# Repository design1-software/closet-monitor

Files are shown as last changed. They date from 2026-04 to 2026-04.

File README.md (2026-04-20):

# Closet Monitor

An end-to-end IoT data pipeline for monitoring my home lab network closet — and the first node in a broader smart-home observability platform built around Home Assistant.

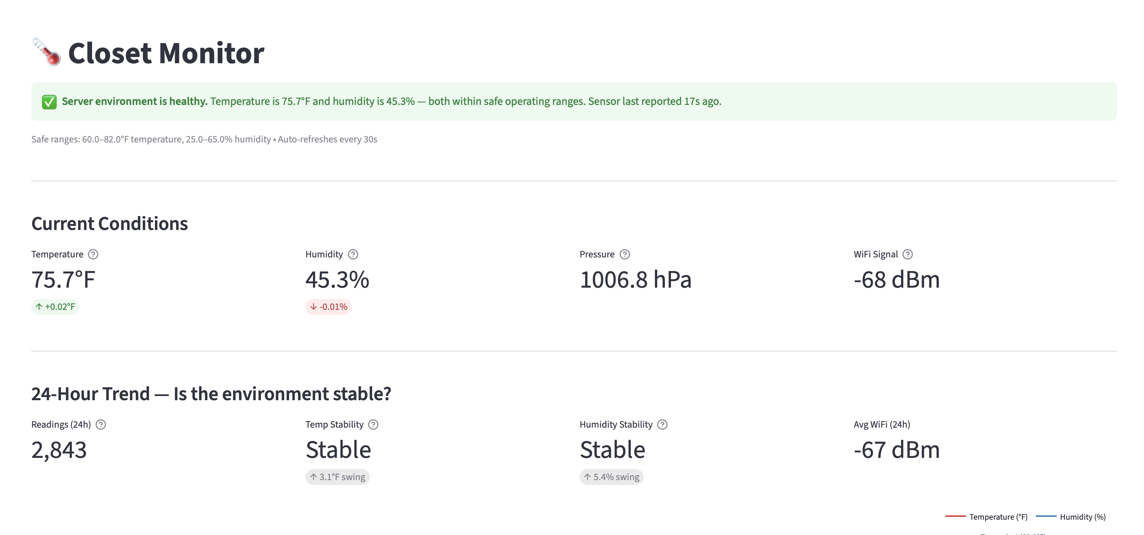
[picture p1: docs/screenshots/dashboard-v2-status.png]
Dashboard Status


*The dashboard leads with the answer: "Should I worry?" Green means all conditions are within safe operating ranges. Current readings, stability assessment, and safe-range thresholds are visible at a glance.*

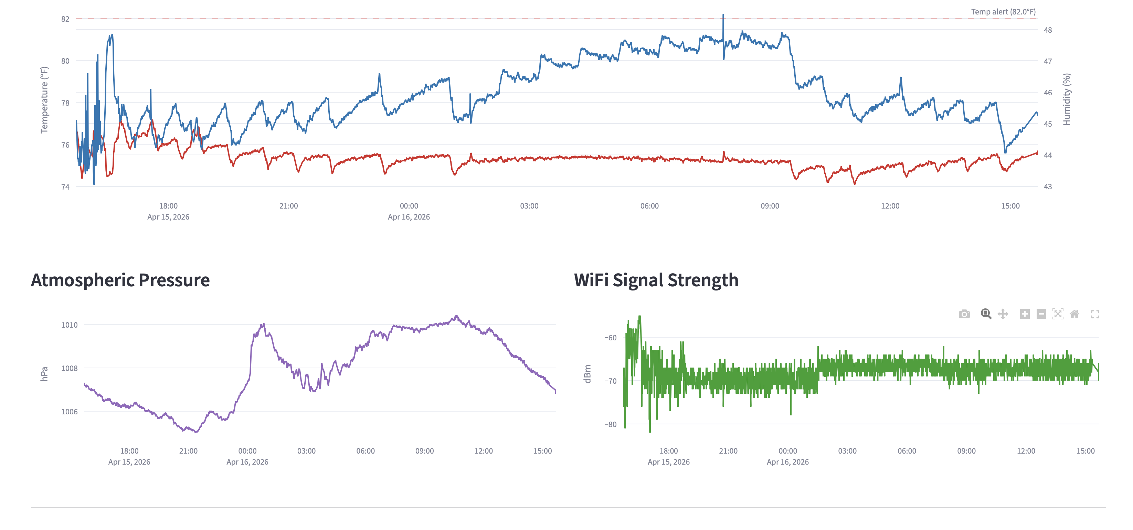
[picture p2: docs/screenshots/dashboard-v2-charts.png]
Dashboard Charts


*24-hour interactive charts for temperature, humidity, pressure, and WiFi signal. The red dashed line marks the 82°F alert threshold — visible context for how close current conditions are to triggering an alert.*

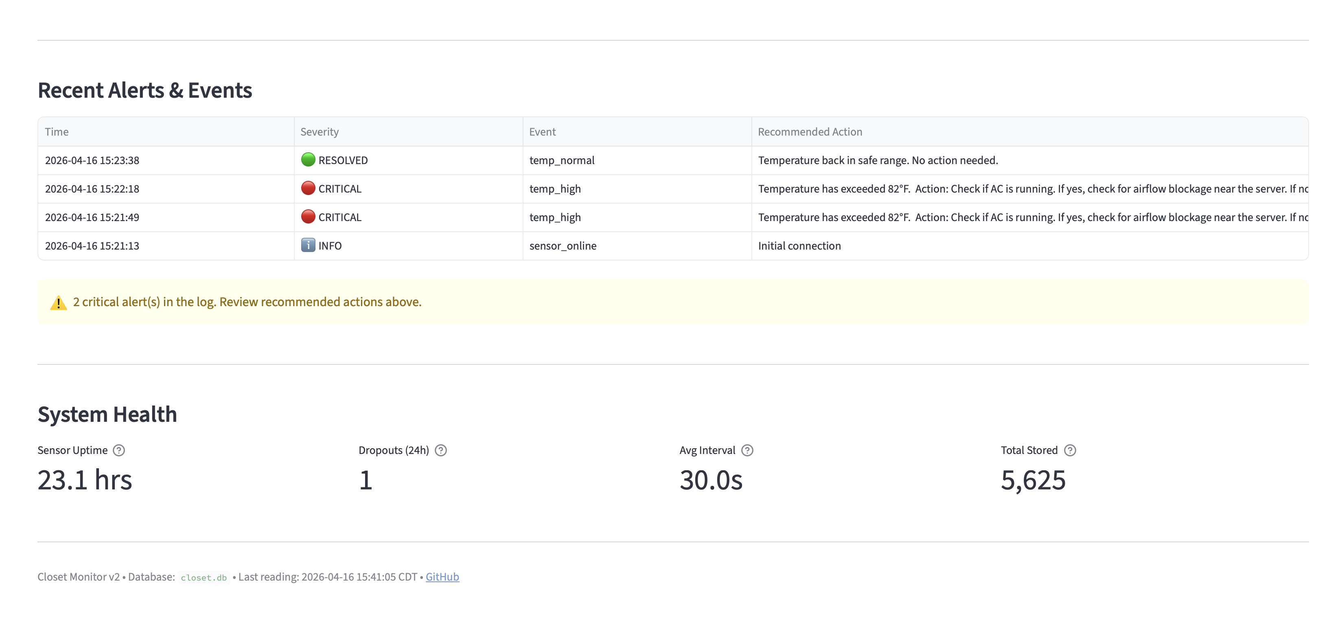
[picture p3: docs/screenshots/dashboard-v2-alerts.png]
Dashboard Alerts


*Incident log with color-coded severity badges and recommended actions for each event. System health metrics at the bottom answer "can I trust this data?" — sensor uptime, dropout count, average interval, total readings stored.*

## The story behind this project

This project started as a single-evening exercise: wire up a microcontroller to a temperature sensor and prove I could do basic embedded work. By the time I had the firmware working and overnight data flowing, I realized the *interesting* problem wasn't the sensor — it was what to do with the telemetry it produced.

So I pivoted.

What was a one-night embedded project became a multi-stage pipeline spanning **embedded systems → networking → backend services → data persistence → exploratory analysis → dashboarding → alerting**. Every layer is a deliberate learning surface. The goal isn't just to monitor my closet — it's to walk a complete data lifecycle with one cohesive dataset I actually understand and care about, then use it as the proving ground for a larger smart-home platform.

The closet is real. My home server lives there, running a production MCP (Model Context Protocol) server and a Meta Engagement automation pipeline. A laptop running 24/7 in an enclosed space deserves observability, and now it has it.

## What this project answers

Every dashboard, alert, and analysis in this project exists to answer a specific question — the same way production monitoring serves stakeholders in a corporate environment.

| Question | Who asks it | How it's answered |
|---|---|---|
| "Is my server environment safe right now?" | Server operator | Dashboard: green/red status banner with plain-English assessment |
| "Has anything happened that requires attention?" | Server operator | Alert listener: macOS notifications with action runbooks + incident log |
| "How efficiently is my HVAC cycling?" | Homeowner | Analysis: cycle frequency, duration, time-of-day patterns |
| "Is the environment stable or volatile?" | Both | Dashboard: stability labels (Stable/Moderate/Volatile) based on 24h swing |
| "What external factors affect my server environment?" | Analyst | Analysis: door events, human presence, time-of-day correlation |
| "Can I trust this monitoring data?" | System operator | Dashboard: sensor uptime, dropout count, average interval |

## Where this is headed

This repo is the foundation for a larger **smart home + home lab observability platform**:

- **Home Assistant on a Raspberry Pi 5** as the central hub, ingesting data from this sensor and other smart devices
- **Ecobee thermostat integration** via Home Assistant, with cross-correlation analysis between the wall thermostat readings and what's actually happening in the closet
- **Three wall-mounted 10-inch tablets** as monitoring and control panels around the house, running Home Assistant's Lovelace UI
- **Multiple sensor projects** feeding into the same data fabric over time

The closet monitor proves out the pipeline pattern. Future sensor projects (door reed switches, motion sensors, current monitors) will reuse this MQTT → broker → database → dashboard architecture.

## Architecture (current)

```
┌─────────────────┐
│  ESP32 + BME280 │  Edge device — embedded C++
└────────┬────────┘
         │ WiFi · MQTT (authenticated)
         ▼
┌─────────────────┐
│ Mosquitto Broker│  Message broker (auth + topic ACLs)
└────────┬────────┘
         │ subscribe (authenticated)
         ▼
┌──────────────────┐    ┌──────────────────┐
│ Python Subscriber│    │  Alert Listener  │
│ paho-mqtt→SQLite │    │ notifications +  │
│                  │    │ runbook actions   │
└────────┬─────────┘    └──────────────────┘
         │
         ▼
┌──────────────────┐
│  SQLite Database │  readings + events + alerts
└────────┬─────────┘
         │
   ┌─────┴─────┬──────────────┐
   ▼           ▼              ▼
Jupyter    Streamlit      MCP tool
analysis   dashboard      (planned)
```

## Architecture (target)

```
┌─────────────────┐    ┌─────────────────┐
│  ESP32 + BME280 │    │ Ecobee Thermostat│
│ (closet sensor) │    │  (whole house)   │
└────────┬────────┘    └────────┬─────────┘
         │ MQTT (TLS)            │ Cloud API
         ▼                       ▼
┌─────────────────────────────────────────┐
│  Home Assistant on Raspberry Pi 5       │
│  + Mosquitto broker (production, TLS)   │
│  + SQLite/Postgres for long-term data   │
└────────┬────────────────────────────────┘
         │
   ┌─────┴──────┬──────────────┬──────────────┐
   ▼            ▼              ▼              ▼
Tablet UIs   Lovelace      Cross-source   AI insights
(3 around    dashboards    analytics      (anomaly
 the house)                (HA + closet)  detection)
```

## Hardware

- **ESP32-WROOM-32** (Teyleten 38-pin, USB-C) — dual-core 240 MHz microcontroller with WiFi + Bluetooth
- **BME280 sensor** (SHILLEHTEK pre-soldered, 3.3V, I²C at 0x76) — temperature, humidity, pressure
- **4 female-to-female Dupont jumper wires** — direct ESP32-to-sensor connection (no breadboard)
- **3D-printable enclosure** — two-piece design (ESP32 cradle + remote sensor pod), STL files in `case-design/`

### Wiring

| BME280 Pin | ESP32 Pin |
|---|---|
| VCC | 3V3 |
| GND | GND |
| SCL | GPIO 22 |
| SDA | GPIO 21 |

## Software stack

- **Firmware:** Arduino C++ using PubSubClient (MQTT) and Adafruit BME280 libraries
- **Broker:** Eclipse Mosquitto 2.x with authentication and topic-level ACLs
- **Subscriber:** Python 3 with paho-mqtt and python-dotenv
- **Alert Listener:** Python 3 with macOS native notifications, action runbooks, SQLite logging
- **Database:** SQLite 3 (readings, events, and alerts tables)
- **Analysis:** Python with pandas, matplotlib, seaborn, scipy (Jupyter notebooks)
- **Dashboard:** Streamlit + Plotly, framed around stakeholder questions
- **Toolchain:** `arduino-cli` for firmware, virtualenv for Python dependencies

## MQTT topics

| Topic | Payload | Frequency |
|---|---|---|
| `home/closet/status` | `online` / `offline` (retained, LWT) | On connect/disconnect |
| `home/closet/environment` | JSON (temp, humidity, pressure, RSSI, uptime) | Every 30s |
| `home/closet/alerts/temperature` | JSON alert state (retained, edge-triggered) | On threshold cross |
| `home/closet/alerts/humidity` | JSON alert state (retained, edge-triggered) | On threshold cross |

The `home/` prefix and standard payload format are intentionally Home Assistant-friendly. When the platform comes online, HA will subscribe to these topics with no firmware changes required.

### Example payload

```json
{
  "temp_f": 76.71,
  "temp_c": 24.84,
  "humidity": 41.44,
  "pressure_hpa": 1009.71,
  "rssi": -72,
  "uptime_s": 60
}
```

## Database schema

```sql
CREATE TABLE readings (
    id              INTEGER PRIMARY KEY AUTOINCREMENT,
    received_at     TEXT NOT NULL,
    device_uptime_s INTEGER,
    temp_f          REAL,
    temp_c          REAL,
    humidity        REAL,
    pressure_hpa    REAL,
    rssi            INTEGER
);

CREATE TABLE events (
    id          INTEGER PRIMARY KEY AUTOINCREMENT,
    received_at TEXT NOT NULL,
    topic       TEXT NOT NULL,
    payload     TEXT NOT NULL
);

CREATE TABLE alerts (
    id          INTEGER PRIMARY KEY AUTOINCREMENT,
    received_at TEXT NOT NULL,
    severity    TEXT NOT NULL,
    event_type  TEXT NOT NULL,
    topic       TEXT NOT NULL,
    payload     TEXT NOT NULL,
    action      TEXT
);
```

## Findings so far

After ~48 hours of continuous operation and 5,600+ readings:

- **Zero packet loss** over the full run (intervals ranged 27.5–32.5s, target 30s)
- Temperature held within a tight 5.4°F band with std dev of just 0.91°F — evidence of healthy HVAC behavior
- **15 HVAC cycles automatically detected** using rolling-mean smoothing + scipy peak detection
- Cycle lengths split into two distinct regimes: **short cycles (16–50 min) during evening peak hours**, **long cycles (100+ min) overnight** — consistent with healthy outside-temperature-driven HVAC behavior
- Average temperature swing per cycle: 1.29°F (tight thermostat control)
- **Rate-of-change anomaly detection** identified 31 rapid temperature events and 67 rapid humidity events using a rolling z-score method
- Detected a **door-closing event at approximately 1:40 AM** from its thermal signature: sudden temperature rise (+1.68°F over 3 minutes) with simultaneous humidity drop, consistent with sealing a warmer, drier room
- Multiple brief humidity spike events (z>10) correlated with human presence and activity in the bedroom

## Alert system

Every alert includes three things: **what happened, why it matters, and what to do about it.**

| Alert | Severity | Action |
|---|---|---|
| Temp > 82°F | CRITICAL | Check if AC is running. If yes, investigate airflow blockage. If no, check thermostat. |
| Temp < 60°F | WARNING | Check if heating is running. Possible HVAC failure. |
| Humidity > 65% | CRITICAL | Check for water intrusion or AC drain issue. Inspect equipment for condensation. |
| Humidity < 25% | WARNING | Consider humidifier. Avoid touching components without grounding. |
| Sensor offline > 5 min | WARNING | Check USB power to ESP32. Check WiFi. Press EN button to reset. |

Alerts are delivered via macOS desktop notifications and logged to both a flat file (`alerts.log`) and the SQLite `alerts` table for dashboard display and historical analysis.

## Security

Defense-in-depth approach: network-layer isolation via Cisco ACLs **plus** application-layer authentication and authorization via Mosquitto.

### Network layer (Cisco ACLs)

The ESP32 sensor will operate on **VLAN 31 (IOT-AUTO)** once the MQTT broker migrates to the Raspberry Pi. The IOT-AUTO ACL restricts traffic to:

- **DNS (UDP/TCP 53)** to Pi-hole only (192.168.10.16)
- **MQTT (TCP 1883, 8883)** to the Pi only (192.168.10.16)
- **All other traffic denied** — no internet, no access to server VLAN, no lateral movement

A compromised ESP32 on IOT-AUTO can only reach the MQTT broker and DNS. It cannot scan the network, access the server, or phone home to an external endpoint.

### Application layer (Mosquitto auth + ACLs)

MQTT connections require username/password authentication. Anonymous access is denied.

| User | Purpose | Permissions |
|---|---|---|
| `closet-sensor` | ESP32 device identity | **Write only** to `home/closet/environment`, `home/closet/status`, `home/closet/alerts/*` |
| `closet-subscriber` | Python services (subscriber + alert listener) | **Read only** on `home/closet/#`, write to `home/closet/status` (for testing) |

**What this prevents:**

| Attack | Without auth | With auth + ACLs |
|---|---|---|
| Rogue device publishes fake "everything is fine" readings | ✅ Possible — anyone on the network can publish | ❌ Blocked — must authenticate, and only `closet-sensor` can write to environment topic |
| Rogue device publishes fake alerts (false CRITICAL notifications) | ✅ Possible | ❌ Blocked — only `closet-sensor` can write to alert topics |
| Rogue device subscribes and eavesdrops on sensor data | ✅ Possible | ❌ Blocked — must authenticate as `closet-subscriber` |
| Compromised subscriber publishes fake readings | ✅ Possible | ❌ Blocked — `closet-subscriber` has read-only access to environment topic |
| Compromised IoT device on VLAN 31 scans the network | ❌ Already blocked by Cisco ACL | ❌ Blocked at network layer before reaching MQTT |

### Credential management

- ESP32 credentials are in `config.h` (gitignored, never committed)
- Python credentials are in `.env` (gitignored, never committed)
- Template files (`config.example.h`, `.env.example`) are committed with placeholder values
- Mosquitto password file uses hashed passwords (not plaintext)

### Encryption roadmap

Currently MQTT traffic is unencrypted (plain TCP on port 1883). When the broker migrates to the Raspberry Pi, TLS will be added:

- Mosquitto configured for MQTT over TLS on port 8883
- ESP32 firmware updated to use `WiFiClientSecure` with certificate pinning
- The IOT-AUTO ACL already permits port 8883 in anticipation of this migration

This will complete the security stack: **network isolation (VLAN + ACL) → authentication (username/password) → authorization (topic ACLs) → encryption (TLS).**

## Setup

### Firmware

1. Copy `config.example.h` to `config.h` and fill in WiFi credentials, MQTT broker IP, and MQTT credentials
2. Install toolchain:
   ```bash
   brew install arduino-cli mosquitto
   arduino-cli core install esp32:esp32
   arduino-cli lib install "PubSubClient" "Adafruit BME280 Library" "Adafruit Unified Sensor"
   ```
3. Compile and upload (hold BOOT button on ESP32 during upload):
   ```bash
   arduino-cli compile --fqbn esp32:esp32:esp32 .
   arduino-cli upload -p /dev/cu.usbserial-0001 --fqbn esp32:esp32:esp32 .
   ```

### Mosquitto broker

```bash
brew install mosquitto
# Create password file with device and subscriber users
mosquitto_passwd -c /opt/homebrew/etc/mosquitto/passwordfile closet-sensor
mosquitto_passwd /opt/homebrew/etc/mosquitto/passwordfile closet-subscriber
# Copy aclfile to /opt/homebrew/etc/mosquitto/aclfile
# Configure mosquitto.conf:
#   listener 1883 0.0.0.0
#   allow_anonymous false
#   password_file /opt/homebrew/etc/mosquitto/passwordfile
#   acl_file /opt/homebrew/etc/mosquitto/aclfile
brew services start mosquitto
```

### Subscriber + Alert Listener

```bash
cd subscriber
python3 -m venv venv
source venv/bin/activate
pip install -r requirements.txt
cp .env.example .env       # edit with your broker IP and MQTT credentials

# Terminal 1: data subscriber
python subscriber.py

# Terminal 2: alert listener
python alert_listener.py
```

### Dashboard

```bash
cd subscriber && source venv/bin/activate
cd ../dashboard
streamlit run dashboard.py
# Opens at http://localhost:8501
```

### Analysis

```bash
cd analysis
jupyter lab
```

### Verify the pipeline

```bash
# Authenticated subscribe (replace credentials)
mosquitto_sub -h <broker-ip> -u closet-subscriber -P '<password>' -t "home/closet/#" -v
sqlite3 data/closet.db "SELECT COUNT(*) FROM readings;"
```

## Design decisions

- **JSON payloads** over binary — slightly more bandwidth, massively easier to debug with `mosquitto_sub -v` and to consume from any language. Also Home Assistant-friendly out of the box.
- **Edge-triggered alerts** — alert topics only publish when state changes, avoiding alert spam while still capturing every transition. Retained flag ensures late subscribers see current state.
- **Last Will & Testament** — broker auto-publishes `offline` to `home/closet/status` if the ESP32 disconnects uncleanly.
- **Non-blocking main loop** — uses `millis()` timing instead of `delay()` so the MQTT client can service keepalives and reconnections between sensor reads.
- **Separation of concerns** — credentials live in `config.h` (firmware) and `.env` (subscriber), both gitignored. Example templates are committed.
- **Server-side timestamps** — the subscriber records `received_at` independently of the device's `uptime_s`, so reading order is preserved even if the device reboots.
- **Runbook-based alerting** — every alert includes a recommended action, not just a notification. This mirrors how production incident management systems (PagerDuty, OpsGenie) operate.
- **Dashboard framed around questions, not metrics** — each section answers a specific stakeholder question ("Should I worry?", "What's the trend?", "Has anything happened?", "Can I trust this data?"). This is how business intelligence dashboards are designed in corporate environments.
- **Defense-in-depth security** — MQTT authentication and topic-level ACLs at the application layer, combined with VLAN isolation and Cisco ACLs at the network layer. Neither layer alone is sufficient; together they prevent both network-level and application-level attacks.
- **SQLite over Postgres for the first iteration** — single-file database, zero ops overhead, sufficient throughput for 30s sampling. Migration to Postgres or DuckDB happens when data volumes or query patterns demand it.
- **MQTT topic naming follows the Home Assistant convention** — `home/<location>/<metric>` — so the eventual HA migration is configuration-only, no firmware changes.

## Repository layout

```
closet-monitor/
├── closet-monitor.ino                 # ESP32 firmware
├── config.example.h                   # Firmware config template
├── case-design/
│   ├── esp32_case.scad                # OpenSCAD source (ESP32 enclosure)
│   ├── esp32_case.stl                 # Print-ready STL
│   ├── sensor_pod.scad                # OpenSCAD source (BME280 pod)
│   ├── sensor_pod.stl                 # Print-ready STL
│   └── PRINT_SPEC.md                 # Print settings and service recommendations
├── data/
│   ├── sample-overnight-*.log         # Sample dataset
│   └── closet.db                      # Live SQLite database (gitignored)
├── subscriber/
│   ├── subscriber.py                  # MQTT → SQLite service (authenticated)
│   ├── alert_listener.py             # Alert notifications + runbook actions (authenticated)
│   ├── requirements.txt               # Python dependencies
│   └── .env.example                   # Config template (includes MQTT credentials)
├── analysis/
│   ├── 01-exploratory-analysis.ipynb  # Exploratory data analysis + HVAC cycle detection
│   └── 02-anomaly-detection.ipynb     # Rate-of-change anomaly detection
├── dashboard/
│   └── dashboard.py                   # Streamlit operations dashboard
├── docs/
│   └── screenshots/                   # README assets
└── README.md
```

## Roadmap

### Done
- [x] ESP32 firmware with WiFi + MQTT + BME280
- [x] Threshold-based alerting (edge-triggered)
- [x] Python subscriber with SQLite persistence
- [x] Sample overnight dataset (~955 readings, 8 hours continuous)
- [x] Exploratory analysis: descriptive stats, time-series plots, correlation
- [x] HVAC cycle detection with scipy peak detection
- [x] Cycle length analysis and time-of-day pattern identification
- [x] Rate-of-change anomaly detection with rolling z-score
- [x] Detected real-world events from sensor signatures (door closing, human presence)
- [x] Streamlit dashboard framed around stakeholder questions
- [x] Alert listener with macOS notifications and action runbooks
- [x] 3D-printable case design (ESP32 enclosure + sensor pod)
- [x] MQTT authentication (per-device username/password)
- [x] MQTT topic-level ACLs (write-only sensor, read-only subscriber)

### Next
- [ ] TLS encryption for MQTT (port 8883) during Pi migration
- [ ] Ecobee integration via Home Assistant HomeKit Controller
- [ ] Cross-correlation analysis: closet temp vs. thermostat schedule
- [ ] AI-generated daily summary reports
- [ ] Migrate broker + services to production server (Acer)

### Platform
- [ ] Install Home Assistant on Raspberry Pi 5
- [ ] Connect HA to existing MQTT topics (zero firmware changes)
- [ ] Add ecobee integration through HA
- [ ] Build Lovelace dashboard combining closet sensor + ecobee data
- [ ] Deploy 3 wall-mounted tablets running HA's tablet UI
- [ ] MCP integration so Claude can query the unified data through HA

### Future sensors
- [ ] PIR motion sensor in the closet
- [ ] Door reed switch on the closet door
- [ ] Current sensor on the home server's power cable
- [ ] Additional environmental nodes in other parts of the house

## Why this lives in one repo

The temptation with a project like this is to split it into multiple repos — one for firmware, one for the subscriber service, one for analysis. I'm deliberately keeping them together because the *story* of this project is the integration. Anyone reading this repo can follow a single physical signal — temperature in a closet — through every stage of an end-to-end data system. That narrative is more valuable to me right now than the modularity. When a piece outgrows this layout (likely the Home Assistant integration), it'll move to its own repo with proper boundaries.

## Related infrastructure

This sensor is one node in a broader home lab network documented at [git-init-home-lab](https://github.com/design1-software/git-init-home-lab).

The ESP32 currently connects via the Gorgeous SSID (VLAN 20, TRUSTED) and publishes MQTT to a Mosquitto broker on the MacBook Pro. When Mosquitto migrates to the Raspberry Pi 4B (192.168.10.16, VLAN 10, SERVER), the ESP32 will move to the Gorgeous-Auto SSID (VLAN 31, IOT-AUTO) — a dedicated automation VLAN that permits only MQTT and DNS traffic to the Pi via Cisco ACLs.

## Author

Julius Moore — part of a broader home lab build, developed alongside coursework for B.S. Software Engineering at WGU.

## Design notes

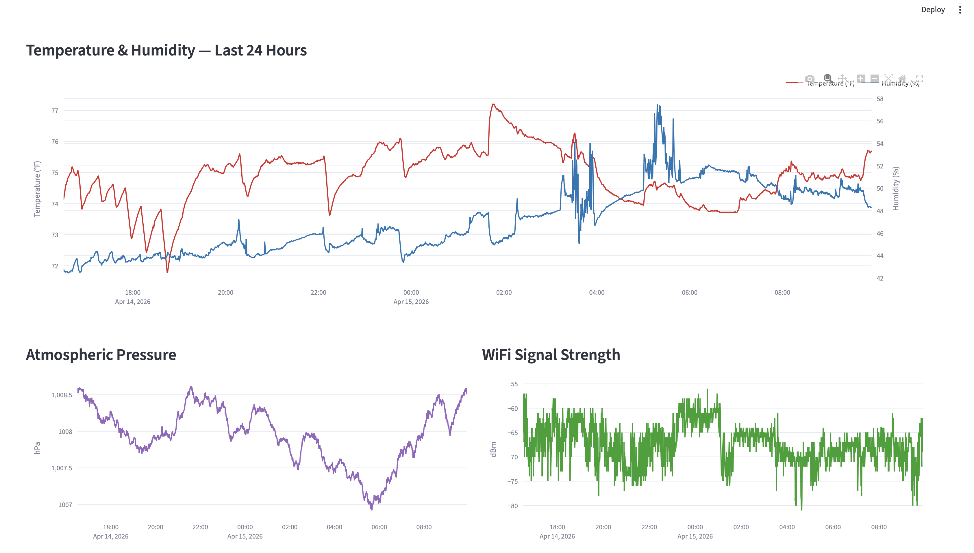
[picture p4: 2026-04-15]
docs/screenshots/hvac-cycles.png

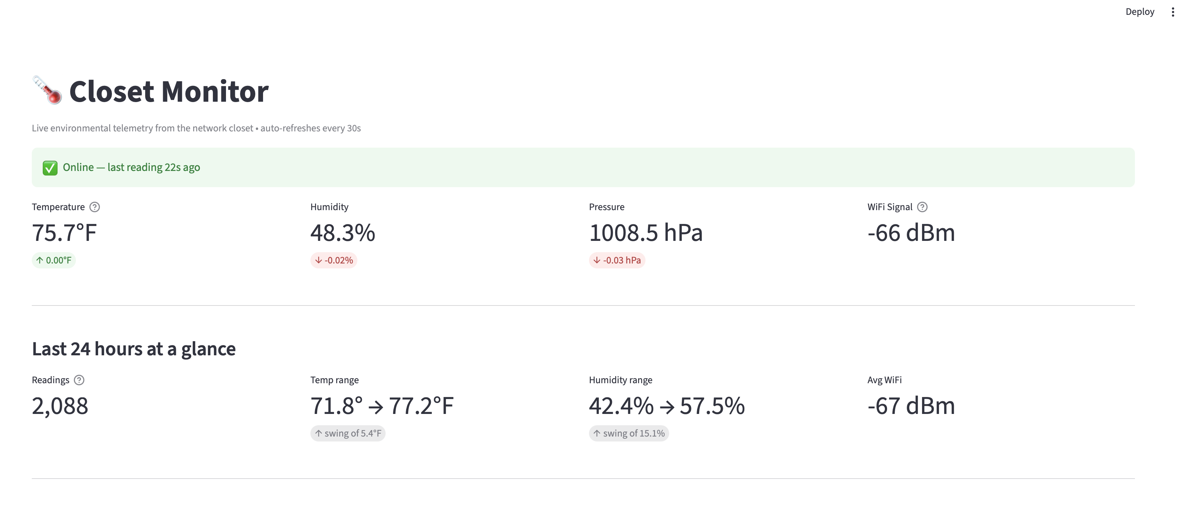
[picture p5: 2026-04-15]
docs/screenshots/dashboard.png

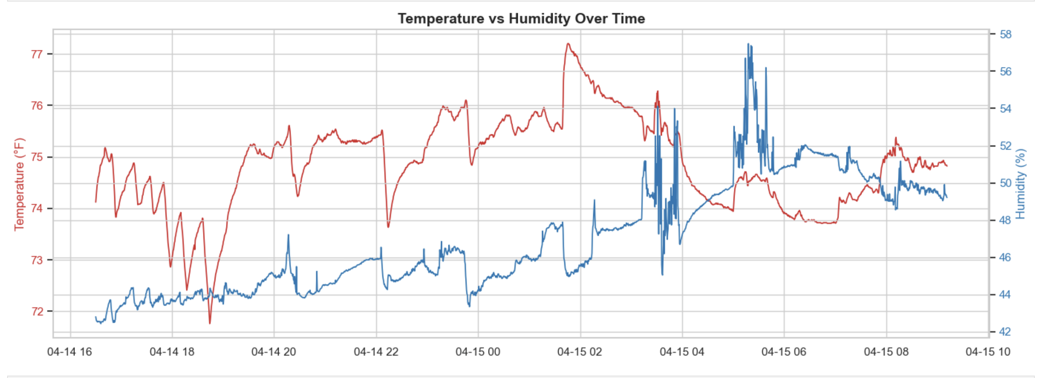
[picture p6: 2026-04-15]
docs/screenshots/time-series.png

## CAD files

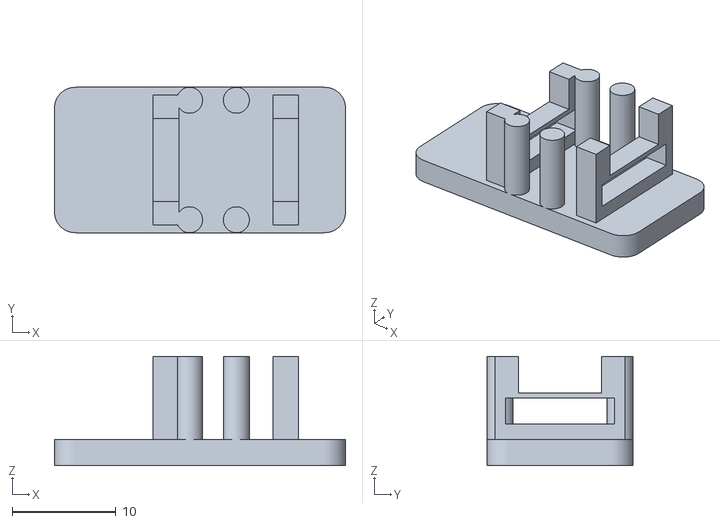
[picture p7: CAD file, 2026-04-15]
case-design/sensor_pod.stl
28.0 x 14.0 x 10.5

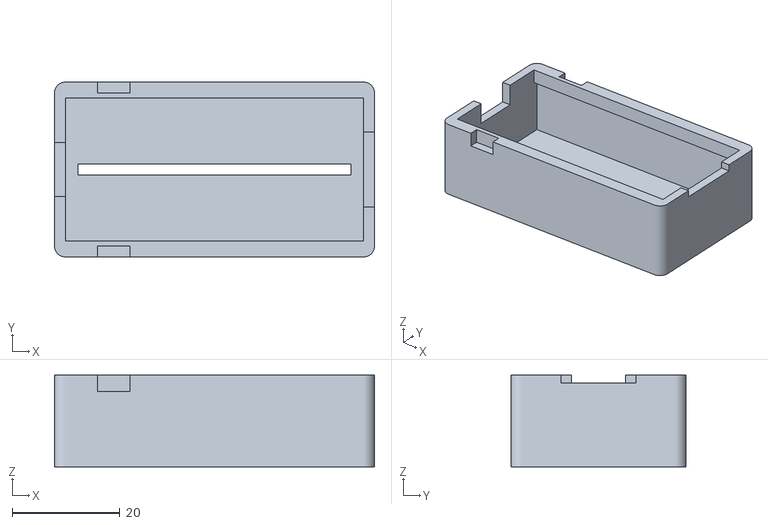
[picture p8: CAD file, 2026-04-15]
case-design/esp32_case.stl
59.5 x 32.5 x 17.1

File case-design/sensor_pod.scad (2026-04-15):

// ============================================================
// BME280 Sensor Pod — Closet Monitor
// ============================================================
// Design: open-air "lantern" style frame that holds the BME280
// breakout board between two end caps with vertical posts —
// maximum airflow on all sides. Flat back for VHB tape.
//
// Board: SHILLEHTEK pre-soldered BME280 breakout
//   Length: ~13mm
//   Width:  ~10mm
//   Thickness: ~2mm with components
//
// Print: PETG, 0.2mm layer, 30% infill, no supports needed
// ============================================================

$fn = 60;

// ---------- TUNABLE PARAMETERS ----------
// BME280 board
board_length = 13.5;
board_width  = 10.5;
board_thick  = 2.5;     // includes the sensor chip on top

// End caps that hold the board
endcap_thick    = 2.5;
endcap_height   = 8;
endcap_width_extra = 2;  // extra width past the board for grip slots

// Posts that connect the two end caps (the "lantern" structure)
post_count   = 4;        // one at each corner
post_diameter = 2.5;
post_spacing  = 9;       // distance between posts (becomes airflow gap)

// Mounting back-plate (flat surface for VHB tape)
backplate_length = 28;
backplate_width  = 14;
backplate_thick  = 2.5;

// Cable exit (where the 4 jumpers come from the ESP32 case)
cable_notch_width  = 8;
cable_notch_height = 4;

// ---------- DERIVED ----------
endcap_total_width = board_width + endcap_width_extra;

// ============================================================
// MAIN ASSEMBLY
// ============================================================
module sensor_pod() {

    // ---------- BACKPLATE (for VHB adhesive mounting) ----------
    translate([-((backplate_length - post_spacing) / 2), -((backplate_width - endcap_total_width) / 2), 0])
        rounded_plate(backplate_length, backplate_width, backplate_thick, r=2);

    // ---------- LEFT END CAP (with PCB slot) ----------
    translate([0, 0, backplate_thick])
        endcap_with_slot();

    // ---------- RIGHT END CAP ----------
    translate([post_spacing + endcap_thick, 0, backplate_thick])
        endcap_with_slot();

    // ---------- CONNECTING POSTS (4 corners) ----------
    // The PCB is held between the two end caps; posts give airflow on all sides
    post_z = backplate_thick;
    post_h = endcap_height;

    // Top-front
    translate([endcap_thick + 1, 0.5, post_z])
        cylinder(h=post_h, d=post_diameter);
    // Top-back
    translate([endcap_thick + 1, endcap_total_width - 0.5, post_z])
        cylinder(h=post_h, d=post_diameter);
    // Bottom-front
    translate([post_spacing - 1, 0.5, post_z])
        cylinder(h=post_h, d=post_diameter);
    // Bottom-back
    translate([post_spacing - 1, endcap_total_width - 0.5, post_z])
        cylinder(h=post_h, d=post_diameter);
}

// End cap with a slot that the BME280 board slides into
module endcap_with_slot() {
    difference() {
        cube([endcap_thick, endcap_total_width, endcap_height]);

        // Slot for the PCB
        translate([-0.5, (endcap_total_width - board_width) / 2, 1.5])
            cube([endcap_thick + 1, board_width, board_thick]);

        // Cable notch on one end cap
        translate([-0.5, (endcap_total_width - cable_notch_width) / 2, endcap_height - cable_notch_height + 0.5])
            cube([endcap_thick + 1, cable_notch_width, cable_notch_height]);
    }
}

// Rounded plate helper
module rounded_plate(l, w, h, r=2) {
    hull() {
        for (x = [r, l - r]) {
            for (y = [r, w - r]) {
                translate([x, y, 0])
                    cylinder(h=h, r=r);
            }
        }
    }
}

// ============================================================
// RENDER
// ============================================================
sensor_pod();

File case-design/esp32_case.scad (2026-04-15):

// ============================================================
// ESP32 Closet Monitor — Main Enclosure
// ============================================================
// Design: side-grip cradle, USB-C accessible, BOOT/EN buttons
// reachable, flat back for 3M VHB tape mounting.
//
// Board: Teyleten ESP32-WROOM-32 38-pin USB-C
//   Length: ~55mm
//   Width:  ~28mm
//   Height: ~13mm (including stacked pin headers below)
//
// Print: PETG, 0.2mm layer, 30% infill, no supports needed
// ============================================================

// ---------- TUNABLE PARAMETERS ----------
$fn = 60;  // smoothness of curves

// Board dimensions (with small clearance)
board_length = 55.5;
board_width  = 28.5;
board_thick  = 1.6;     // PCB only
pin_clearance = 12;     // space below board for pin headers

// Wall thickness
wall = 2.0;

// Side rails that grip the PCB
rail_height = 1.5;      // how much the rail sticks up over the PCB top
rail_grip   = 1.0;      // how far the rail extends inward over the PCB

// USB-C cutout (left end of board)
usb_width  = 10;
usb_height = 5;
usb_y_offset = 0;       // centered on board height

// Cable exit slot for the 4 sensor jumper wires (right end)
cable_slot_width  = 14;
cable_slot_height = 6;

// Button access cutouts (BOOT and EN are on opposite sides near the USB end)
button_cutout_width  = 6;
button_cutout_height = 5;
button_y_from_usb_end = 8;  // approx distance from USB end to buttons

// Vent slots on the bottom (so heat from the regulator can escape)
vent_count = 4;
vent_width = 2;
vent_length = 15;

// ---------- DERIVED ----------
inner_length = board_length;
inner_width  = board_width;
outer_length = inner_length + (2 * wall);
outer_width  = inner_width  + (2 * wall);
outer_height = pin_clearance + board_thick + rail_height + wall;

// ============================================================
// MAIN BODY
// ============================================================
module esp32_case() {
    difference() {
        // Solid outer shell
        rounded_box(outer_length, outer_width, outer_height, r=2);

        // Hollow out the interior cavity (where pin headers live)
        translate([wall, wall, wall])
            cube([inner_length, inner_width, pin_clearance + board_thick + rail_height + 1]);

        // USB-C cutout (one end)
        translate([-1, (outer_width - usb_width) / 2, wall + pin_clearance + (board_thick - usb_height)/2])
            cube([wall + 2, usb_width, usb_height + 2]);

        // Cable exit slot (opposite end, raised so wires exit above the PCB)
        translate([outer_length - wall - 1, (outer_width - cable_slot_width)/2, wall + pin_clearance + board_thick])
            cube([wall + 2, cable_slot_width, cable_slot_height]);

        // BOOT button access (one side, near USB end)
        translate([button_y_from_usb_end, -1, wall + pin_clearance])
            cube([button_cutout_width, wall + 2, button_cutout_height]);

        // EN button access (opposite side, near USB end)
        translate([button_y_from_usb_end, outer_width - wall - 1, wall + pin_clearance])
            cube([button_cutout_width, wall + 2, button_cutout_height]);

        // Bottom vent slots (for AMS1117 voltage regulator heat)
        for (i = [0 : vent_count - 1]) {
            x_pos = (outer_length / (vent_count + 1)) * (i + 1) - vent_length/2;
            translate([x_pos, (outer_width - vent_width)/2, -1])
                cube([vent_length, vent_width, wall + 2]);
        }
    }

    // ---------- INTERNAL SIDE RAILS THAT GRIP THE PCB ----------
    // The PCB rests on these ledges; the lip above holds it down
    rail_z = wall + pin_clearance;

    // Long-edge rails (front and back of the cradle)
    translate([wall, wall - 0.01, rail_z])
        side_rail(inner_length, rail_grip, board_thick + rail_height);

    translate([wall, outer_width - wall - rail_grip + 0.01, rail_z])
        side_rail(inner_length, rail_grip, board_thick + rail_height);
}

// A side rail that the PCB edge slides into
module side_rail(length, depth, height) {
    cube([length, depth, height]);
}

// Rounded box helper
module rounded_box(l, w, h, r=2) {
    hull() {
        for (x = [r, l - r]) {
            for (y = [r, w - r]) {
                translate([x, y, 0])
                    cylinder(h=h, r=r);
            }
        }
    }
}

// ============================================================
// RENDER
// ============================================================
esp32_case();

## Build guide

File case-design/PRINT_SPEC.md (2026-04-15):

# Closet Monitor — 3D Print Specification

Two-piece enclosure for an ESP32-based environmental monitor: a main case for the ESP32 dev board and a remote sensor pod for the BME280, designed to maximize airflow around the sensor.

## Files in this package

| File | Description |
|---|---|
| `esp32_case.scad` | OpenSCAD source for the main ESP32 enclosure |
| `esp32_case.stl` | Print-ready STL of the main enclosure |
| `sensor_pod.scad` | OpenSCAD source for the BME280 sensor pod |
| `sensor_pod.stl` | Print-ready STL of the sensor pod |
| `PRINT_SPEC.md` | This file |

## Recommended print settings

| Setting | Value | Notes |
|---|---|---|
| **Material** | PETG | More heat-tolerant than PLA (closet may warm in summer) |
| **Color** | Black or dark gray | Hides dust, looks professional |
| **Layer height** | 0.2 mm | Standard quality, good detail |
| **Infill** | 30% | Strong enough; no need for solid |
| **Wall thickness** | 1.2 mm (3 perimeters) | Sturdy without bulk |
| **Top/bottom layers** | 4 | Clean appearance |
| **Supports** | None required | Designed to print support-free |
| **Build plate adhesion** | Brim recommended | Small parts, prevents lift |
| **Print orientation** | Both parts: largest flat side down | Optimal layer adhesion |

## Estimated print details

| Part | Approx. dimensions | Print time | Filament |
|---|---|---|---|
| ESP32 case | 60 × 33 × 22 mm | ~1.5 hours | ~15 g |
| Sensor pod | 30 × 14 × 13 mm | ~30 min | ~5 g |
| **Total** | — | **~2 hours** | **~20 g** |

## Recommended print services

If you don't own a 3D printer:

- **Craftcloud** (craftcloud3d.com) — aggregator, gets you the best price across multiple services
- **JLCPCB** (jlcpcb.com) — very cheap, ships from China, ~2 weeks delivery
- **Treatstock** (treatstock.com) — local printers in the US, faster delivery
- **Shapeways** (shapeways.com) — premium quality, more expensive

Expected total cost: **$8–15** including shipping for both parts in PETG.

## Design notes

### ESP32 main case
- **Side-rail cradle:** the PCB slides in by its long edges and is held by inward-facing rails on top, leaving the bottom pin headers free in the cavity below
- **USB-C cutout:** on one short end, sized for standard USB-C cables
- **Cable exit slot:** opposite end, sized to accept the 4 jumper wires going to the sensor pod
- **Button cutouts:** BOOT and EN buttons are accessible through openings on the long sides
- **Bottom vent slots:** four small slots underneath let heat from the AMS1117 voltage regulator escape
- **Flat back:** for 3M VHB (or similar double-sided) tape mounting

### Sensor pod
- **Open "lantern" frame:** two end caps connected by four corner posts, leaving the BME280 surrounded by air on all sides
- **Slot-mounted PCB:** the breakout board slides into matching slots in the end caps
- **Cable notch:** on one end cap for the 4 jumper wires
- **Backplate:** flat surface for VHB tape mounting; designed to sit a few inches away from the ESP32 case so the sensor isn't influenced by ESP32 heat

## Mounting

Both pieces are designed for **3M VHB tape (or any flat double-sided foam tape)** mounted on a wall, patch panel, or shelf surface. The sensor pod should be placed **a few inches away from the ESP32 case** to ensure airflow around the sensor isn't influenced by the warmth of the microcontroller.

## Customization

The `.scad` files are fully parameterized — you can adjust:
- Board dimensions if using a different ESP32 variant
- Wall thickness, vent count, button positions
- Backplate size for different mounting needs

Edit the values at the top of each `.scad` file in OpenSCAD (free download at openscad.org), then re-export as STL.

## Author

Designed for the [closet-monitor](https://github.com/design1-software/closet-monitor) project by Julius Moore.

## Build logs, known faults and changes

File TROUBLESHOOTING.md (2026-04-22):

# Closet Monitor — Troubleshooting Runbook

A step-by-step guide for diagnosing and recovering from common issues. Work through the sections in order — each step builds on the previous one.

---

## Quick health check (run this first)

Open a terminal and run all five commands. The output tells you exactly what's broken.

```bash
# 1. Is Mosquitto broker running?
brew services list | grep mosquitto

# 2. Is the Python subscriber running?
ps aux | grep subscriber.py | grep -v grep

# 3. Is the alert listener running?
ps aux | grep alert_listener.py | grep -v grep

# 4. What is my Mac's current IP?
ipconfig getifaddr en0

# 5. Is the ESP32 publishing? (waits 15 seconds for one message)
mosquitto_sub -h $(ipconfig getifaddr en0) -u closet-subscriber -P 'YOUR_PASSWORD' -t "home/closet/#" -C 1 -W 15
```

### Reading the results

| Check | Healthy | Broken |
|---|---|---|
| Mosquitto | `started` | `none` or `stopped` |
| Subscriber | Shows a python process with PID | No output |
| Alert listener | Shows a python process with PID | No output |
| Mac IP | Shows an IP like `192.168.20.25` | No output (not connected to WiFi) |
| ESP32 publishing | Prints a JSON reading within 15s | Times out with no output |

---

## Problem: Dashboard says sensor is offline

**Most common cause:** the subscriber stopped running. The dashboard reads from the SQLite database, and the subscriber is what writes to it. If the subscriber isn't running, no new data arrives, and the dashboard shows the sensor as offline.

### Fix

```bash
# Check if subscriber is running
ps aux | grep subscriber.py | grep -v grep

# If nothing shows up, restart it
cd ~/Documents/closet-monitor/subscriber
source venv/bin/activate
python subscriber.py &

# Verify it connected
# (wait 5 seconds, you should see "Connected to MQTT broker" and "Stored reading" lines)
```

---

## Problem: Subscriber won't connect ("Not authorized")

**Cause:** MQTT credentials are wrong or the password has special characters not properly quoted.

### Fix

```bash
# Check .env file
cat ~/Documents/closet-monitor/subscriber/.env | grep MQTT

# Verify the password is in single quotes if it contains ! $ # or other special chars
# CORRECT:   MQTT_PASSWORD='MyPassword!!'
# WRONG:     MQTT_PASSWORD=MyPassword!!

# Edit if needed
nano ~/Documents/closet-monitor/subscriber/.env

# Restart subscriber
kill %1 2>/dev/null
python subscriber.py &
```

### Test credentials manually

```bash
mosquitto_sub -h $(ipconfig getifaddr en0) -u closet-subscriber -P 'YOUR_PASSWORD' -t "home/closet/#" -C 1 -W 10
```

If this returns "not authorised", the password doesn't match what's in Mosquitto's password file. Recreate it:

```bash
cd /opt/homebrew/etc/mosquitto
mosquitto_passwd passwordfile closet-subscriber
# Enter new password when prompted
brew services restart mosquitto
# Then update .env with the new password
```

---

## Problem: Mosquitto broker is not running

### Fix

```bash
# Check status
brew services list | grep mosquitto

# If stopped, start it
brew services start mosquitto

# If it was already "started" but not actually listening, restart
brew services restart mosquitto

# Verify it's listening on port 1883
sudo lsof -i :1883
# Should show: mosquitto ... *:1883 (LISTEN)
```

### If Mosquitto won't start

```bash
# Check for config errors by running manually with verbose output
brew services stop mosquitto
/opt/homebrew/opt/mosquitto/sbin/mosquitto -c /opt/homebrew/etc/mosquitto/mosquitto.conf -v

# Look for error messages — common issues:
# - "Error: Unable to open password file" → path is wrong in mosquitto.conf
# - "Error: Unable to open acl file" → path is wrong in mosquitto.conf
# - "Error: Address already in use" → another process is on port 1883

# Fix the issue, then restart normally
brew services start mosquitto
```

---

## Problem: ESP32 is not publishing (mosquitto_sub times out)

The ESP32 is either powered off, not connected to WiFi, or trying to reach the wrong broker IP.

### Step 1: Physical check

Go to the closet and look at the ESP32:

- **Red power LED on?** If no → USB cable is loose or wall charger isn't working. Reseat the cable or try a different charger.
- **Red LED on but no blue LED activity?** The ESP32 is powered but may be stuck. Press the **EN button** (small button near the USB port) to reboot it. Wait 10 seconds, then check `mosquitto_sub` again.

### Step 2: WiFi check

If the ESP32 is powered and rebooted but still not publishing, it may have lost WiFi.

**Common causes:**
- WiFi password changed → need to reflash firmware with new password
- Router rebooted and ESP32 hasn't reconnected → press EN to reboot ESP32
- WiFi SSID changed → need to reflash firmware
- ESP32 is too far from the access point → check RSSI in recent readings, should be above -85 dBm

### Step 3: Broker IP check

If your Mac's IP changed (check with `ipconfig getifaddr en0`), the ESP32 is trying to publish to the old IP.

**Fix:** reflash the ESP32 with the new broker IP:

```bash
# Update config.h with new MQTT_HOST IP
nano ~/Documents/closet-monitor/config.h

# Bring ESP32 to the Mac, plug in via USB-C
cd ~/Documents/closet-monitor
arduino-cli compile --fqbn esp32:esp32:esp32 .
arduino-cli upload -p /dev/cu.usbserial-0001 --fqbn esp32:esp32:esp32 .
# Hold BOOT button when you see "Connecting......"

# Verify it reconnects
mosquitto_sub -h $(ipconfig getifaddr en0) -u closet-subscriber -P 'YOUR_PASSWORD' -t "home/closet/#" -C 1

# Move ESP32 back to closet wall charger
```

**Prevention:** set a static IP reservation for your Mac in your router's DHCP settings so the IP never changes.

---

## Problem: Mac's IP address changed

**Cause:** DHCP assigned a different IP after a reboot, network switch, or lease expiration.

**What breaks:** the ESP32 firmware has the broker IP hardcoded. If the Mac's IP changes, the ESP32 publishes to the old IP and nothing arrives.

### Fix

```bash
# Check current IP
ipconfig getifaddr en0

# If different from what's in config.h, you need to:
# 1. Update config.h with the new IP
# 2. Reflash the ESP32 (see "Broker IP check" above)
# 3. Update .env with the new MQTT_HOST
# 4. Restart subscriber and alert listener
```

### Prevention

Set a static DHCP reservation in your router for your Mac's MAC address. This ensures the same IP is assigned every time.

---

## Problem: Dashboard won't start ("command not found: streamlit")

**Cause:** the Python virtual environment isn't activated.

### Fix

```bash
cd ~/Documents/closet-monitor/subscriber
source venv/bin/activate
cd ~/Documents/closet-monitor/dashboard
streamlit run dashboard.py
```

Always activate the venv first — Streamlit is installed there, not globally.

---

## Problem: Dashboard shows stale data (no new readings)

**Cause:** subscriber crashed or disconnected silently.

### Fix

```bash
# Kill any existing subscriber
ps aux | grep subscriber.py | grep -v grep
# Note the PID, then:
kill <PID>

# Restart
cd ~/Documents/closet-monitor/subscriber
source venv/bin/activate
python subscriber.py &

# Watch for "Stored reading" lines to confirm data is flowing
```

---

## Problem: Alert listener not sending notifications

### Fix

```bash
# Check if alert listener is running
ps aux | grep alert_listener.py | grep -v grep

# If not running, start it
cd ~/Documents/closet-monitor/subscriber
source venv/bin/activate
python alert_listener.py &

# Test with a simulated alert
mosquitto_pub -h $(ipconfig getifaddr en0) -u closet-sensor -P 'SENSOR_PASSWORD' -t "home/closet/alerts/temperature" -m '{"alert":true,"temp_f":86.0,"threshold_high":85.0,"threshold_low":50.0}'

# You should see a macOS notification banner appear
```

---

## Problem: Mac rebooted — what needs restarting?

After a Mac reboot, this is the recovery sequence:

```bash
# Step 1: Mosquitto auto-starts via brew services — verify
brew services list | grep mosquitto
# If not started: brew services start mosquitto

# Step 2: Start the subscriber
cd ~/Documents/closet-monitor/subscriber
source venv/bin/activate
python subscriber.py &

# Step 3: Start the alert listener
python alert_listener.py &

# Step 4: Verify ESP32 is publishing
mosquitto_sub -h $(ipconfig getifaddr en0) -u closet-subscriber -P 'YOUR_PASSWORD' -t "home/closet/#" -C 1

# Step 5: Keep Mac awake (if needed)
caffeinate -dims &

# Step 6: Launch dashboard (optional — only when you want to view it)
cd ~/Documents/closet-monitor/dashboard
streamlit run dashboard.py
```

**Note:** Mosquitto auto-starts on reboot (brew service). The subscriber and alert listener do NOT — they must be started manually each time. This will be resolved when services migrate to the Acer or Pi with proper service management.

---

## Problem: Serial port locked ("screen is terminating" or "resource busy")

**Cause:** a previous `screen` session or Arduino upload is holding the serial port.

### Fix

```bash
# Find what's holding the port
sudo lsof /dev/cu.usbserial-0001

# Kill the process
sudo kill -9 <PID>

# Clean up orphaned screen sessions
screen -wipe
pkill screen

# Verify port is free (should return nothing)
sudo lsof /dev/cu.usbserial-0001
```

---

## Full system restart (nuclear option)

If everything seems broken and you want a clean start:

```bash
# 1. Kill everything
pkill -f subscriber.py
pkill -f alert_listener.py
pkill -f streamlit
brew services stop mosquitto

# 2. Restart Mosquitto
brew services start mosquitto

# 3. Verify broker is listening
sudo lsof -i :1883

# 4. Physically reboot the ESP32 (press EN button or unplug/replug power)

# 5. Verify ESP32 is publishing
mosquitto_sub -h $(ipconfig getifaddr en0) -u closet-subscriber -P 'YOUR_PASSWORD' -t "home/closet/#" -C 1 -W 30

# 6. Start subscriber
cd ~/Documents/closet-monitor/subscriber
source venv/bin/activate
python subscriber.py &

# 7. Start alert listener
python alert_listener.py &

# 8. Keep Mac awake
caffeinate -dims &

# 9. Launch dashboard
cd ~/Documents/closet-monitor/dashboard
streamlit run dashboard.py

# 10. Verify dashboard shows green status at http://localhost:8501
```

---

## Reference: key file locations

| File | Path | Purpose |
|---|---|---|
| ESP32 firmware | `~/Documents/closet-monitor/closet-monitor.ino` | Sensor code |
| ESP32 config (secrets) | `~/Documents/closet-monitor/config.h` | WiFi + MQTT credentials |
| Mosquitto config | `/opt/homebrew/etc/mosquitto/mosquitto.conf` | Broker settings |
| Mosquitto passwords | `/opt/homebrew/etc/mosquitto/passwordfile` | Hashed MQTT credentials |
| Mosquitto ACLs | `/opt/homebrew/etc/mosquitto/aclfile` | Topic permissions |
| Python subscriber | `~/Documents/closet-monitor/subscriber/subscriber.py` | MQTT → SQLite |
| Alert listener | `~/Documents/closet-monitor/subscriber/alert_listener.py` | Alerts + notifications |
| Python config (secrets) | `~/Documents/closet-monitor/subscriber/.env` | MQTT credentials |
| SQLite database | `~/Documents/closet-monitor/data/closet.db` | All readings + alerts |
| Alert log | `~/Documents/closet-monitor/data/alerts.log` | Flat-file alert history |
| Dashboard | `~/Documents/closet-monitor/dashboard/dashboard.py` | Streamlit UI |
| Virtual environment | `~/Documents/closet-monitor/subscriber/venv/` | Python dependencies |

## Reference: key commands

| Task | Command |
|---|---|
| Check Mac IP | `ipconfig getifaddr en0` |
| Check broker status | `brew services list \| grep mosquitto` |
| Check subscriber | `ps aux \| grep subscriber.py \| grep -v grep` |
| Grab one reading | `mosquitto_sub -h $(ipconfig getifaddr en0) -u closet-subscriber -P 'PWD' -t "home/closet/#" -C 1` |
| Count total readings | `sqlite3 ~/Documents/closet-monitor/data/closet.db "SELECT COUNT(*) FROM readings;"` |
| Recent readings | `sqlite3 ~/Documents/closet-monitor/data/closet.db "SELECT * FROM readings ORDER BY id DESC LIMIT 5;"` |
| Recent alerts | `sqlite3 ~/Documents/closet-monitor/data/closet.db "SELECT * FROM alerts ORDER BY id DESC LIMIT 5;"` |
| Compile firmware | `cd ~/Documents/closet-monitor && arduino-cli compile --fqbn esp32:esp32:esp32 .` |
| Flash firmware | `arduino-cli upload -p /dev/cu.usbserial-0001 --fqbn esp32:esp32:esp32 .` |
| Start dashboard | `cd ~/Documents/closet-monitor/subscriber && source venv/bin/activate && cd ../dashboard && streamlit run dashboard.py` |

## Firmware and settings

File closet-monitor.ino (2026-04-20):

/*
 * Closet Environmental Monitor
 * ----------------------------
 * ESP32 + BME280 sensor publishing environmental data to an MQTT broker.
 * Part of a home lab infrastructure monitoring system.
 *
 * Publishes:
 *   home/closet/environment        - Regular readings every PUBLISH_INTERVAL_MS
 *   home/closet/alerts/temperature - When temp crosses configured thresholds
 *   home/closet/alerts/humidity    - When humidity crosses configured thresholds
 *   home/closet/status             - Online/offline status (LWT)
 *
 * Author: Julius Moore
 * Hardware: ESP32-WROOM-32 (Teyleten 38-pin) + BME280 (I2C, 0x76)
 */

 #include <WiFi.h>
 #include <PubSubClient.h>
 #include <Wire.h>
 #include <Adafruit_Sensor.h>
 #include <Adafruit_BME280.h>
 #include "config.h"
 
 // ----- Globals -----
 WiFiClient   espClient;
 PubSubClient mqtt(espClient);
 Adafruit_BME280 bme;
 
 unsigned long lastPublish = 0;
 bool lastTempAlertState = false;
 bool lastHumidityAlertState = false;
 
 // ----- WiFi -----
 void connectWiFi() {
   Serial.printf("Connecting to WiFi: %s ", WIFI_SSID);
   WiFi.mode(WIFI_STA);
   WiFi.begin(WIFI_SSID, WIFI_PASSWORD);
 
   unsigned long start = millis();
   while (WiFi.status() != WL_CONNECTED && millis() - start < 20000) {
     delay(500);
     Serial.print(".");
   }
 
   if (WiFi.status() == WL_CONNECTED) {
     Serial.printf("\nConnected. IP: %s, RSSI: %d dBm\n",
                   WiFi.localIP().toString().c_str(), WiFi.RSSI());
   } else {
     Serial.println("\nWiFi connection failed. Will retry in main loop.");
   }
 }
 
 // ----- MQTT -----
 void connectMQTT() {
   mqtt.setServer(MQTT_HOST, MQTT_PORT);
 
   while (!mqtt.connected()) {
     Serial.printf("Connecting to MQTT %s:%d ... ", MQTT_HOST, MQTT_PORT);
 
     // Last Will & Testament: broker publishes "offline" if we disconnect uncleanly
     if (mqtt.connect(MQTT_CLIENT_ID,
                      MQTT_USER, MQTT_PASSWORD,
                      "home/closet/status", 1, true, "offline")) {
       Serial.println("connected.");
       mqtt.publish("home/closet/status", "online", true);
     } else {
       Serial.printf("failed, rc=%d. Retrying in 5s\n", mqtt.state());
       delay(5000);
     }
   }
 }
 
 // ----- Sensor reading + publish -----
 void readAndPublish() {
   float tempC = bme.readTemperature();
   float tempF = tempC * 9.0 / 5.0 + 32.0;
   float humidity = bme.readHumidity();
   float pressure = bme.readPressure() / 100.0;  // hPa
 
   // Build JSON payload
   char payload[200];
   snprintf(payload, sizeof(payload),
            "{\"temp_f\":%.2f,\"temp_c\":%.2f,\"humidity\":%.2f,"
            "\"pressure_hpa\":%.2f,\"rssi\":%d,\"uptime_s\":%lu}",
            tempF, tempC, humidity, pressure, WiFi.RSSI(), millis() / 1000);
 
   if (mqtt.publish("home/closet/environment", payload)) {
     Serial.printf("Published: %s\n", payload);
   } else {
     Serial.println("Publish failed.");
   }
 
   // ----- Threshold alerts (edge-triggered: only publish on state change) -----
   bool tempAlert = (tempF > TEMP_HIGH_F) || (tempF < TEMP_LOW_F);
   if (tempAlert != lastTempAlertState) {
     char alertMsg[150];
     snprintf(alertMsg, sizeof(alertMsg),
              "{\"alert\":%s,\"temp_f\":%.2f,\"threshold_high\":%.2f,\"threshold_low\":%.2f}",
              tempAlert ? "true" : "false", tempF, TEMP_HIGH_F, TEMP_LOW_F);
     mqtt.publish("home/closet/alerts/temperature", alertMsg, true);
     Serial.printf("TEMP ALERT: %s\n", alertMsg);
     lastTempAlertState = tempAlert;
   }
 
   bool humidityAlert = (humidity > HUMIDITY_HIGH_PCT) || (humidity < HUMIDITY_LOW_PCT);
   if (humidityAlert != lastHumidityAlertState) {
     char alertMsg[150];
     snprintf(alertMsg, sizeof(alertMsg),
              "{\"alert\":%s,\"humidity\":%.2f,\"threshold_high\":%.2f,\"threshold_low\":%.2f}",
              humidityAlert ? "true" : "false", humidity, HUMIDITY_HIGH_PCT, HUMIDITY_LOW_PCT);
     mqtt.publish("home/closet/alerts/humidity", alertMsg, true);
     Serial.printf("HUMIDITY ALERT: %s\n", alertMsg);
     lastHumidityAlertState = humidityAlert;
   }
 }
 
 // ----- Setup -----
 void setup() {
   Serial.begin(115200);
   delay(1000);
   Serial.println("\n=== Closet Monitor starting ===");
 
   Wire.begin(21, 22);  // SDA=21, SCL=22
   if (!bme.begin(0x76) && !bme.begin(0x77)) {
     Serial.println("BME280 not found! Halting.");
     while (1) delay(1000);
   }
   Serial.println("BME280 initialized.");
 
   connectWiFi();
   connectMQTT();
 }
 
 // ----- Main loop -----
 void loop() {
   if (WiFi.status() != WL_CONNECTED) connectWiFi();
   if (!mqtt.connected()) connectMQTT();
   mqtt.loop();
 
   if (millis() - lastPublish >= PUBLISH_INTERVAL_MS) {
     readAndPublish();
     lastPublish = millis();
   }
 }

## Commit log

2026-04-14 Initial commit: ESP32 + BME280 closet monitor with MQTT
2026-04-14 Add overnight dataset sample: ~8hr continuous run, ~955 readings
2026-04-15 Enhance README with visuals and updated findings
    Three meaningful changes:
    Dashboard screenshot at the very top, right after the title. Anyone landing on the repo sees a working, polished dashboard before reading a single word of code or documentation. That's the strongest 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
    HVAC cycle detection chart embedded in the Findings section, with a caption explaining what they're looking at. This is the proof that you're not just collecting data — you're extracting insight from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
    Time-series chart embedded right after, showing the dual-axis temp/humidity view with a callout to the inflection point. This is your data-storytelling artifact..
2026-04-15 Add streamlit and plotly to subscriber requirements; scaffold case-design directory
2026-04-15 Add 3D case design files: ESP32 enclosure and sensor pod (STL + OpenSCAD)
    [esp32_case.scad, esp32_case.stl, sensor_pod.scad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]
2026-05-07 Update requirements.txt and rewrite TROUBLESHOOTING.md for Windows/Acer
    requirements.txt: replace macOS/Python 3.12 lockfile with pip freeze from
    working Windows venv (Python 3.11.9 on Acer). Removes incompatible packages
    (ipython==9.12.0, appnope, pexpect, ptyprocess, terminado, full Jupyter stack).
    TROUBLESHOOTING.md: full rewrite for current architecture — all macOS commands
    (brew, ipconfig getifaddr, osascript, caffeinate, ps aux) replaced with
    Windows/PowerShell equivalents. Reflects actual component locations: Mosquitto
    on Pi (192.168.10.16), services on Acer (192.168.10.11), logs in data/logs/,
    startup via start-services.ps1 and ClosetMonitorServices scheduled task.
    Co-Authored-By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
2026-05-07 Update README to reflect current Acer/Pi production architecture
    - Architecture diagram: shows Pi (192.168.10.16) as broker, Acer (192.168.10.11)
    as subscriber/dashboard host, VLAN assignments, dashboard port
    - Software stack: broker location, alert delivery (winotify + ntfy), dashboard URL,
    service management via Scheduled Task + start-services.ps1
    - Alert system: replace macOS notification description with winotify + ntfy
    - Security: remove future-tense language around Pi migration (already done),
    TLS encryption roadmap updated accordingly
    - Setup: all commands rewritten for Windows/PowerShell and Pi SSH;
    removes brew, macOS paths, and source venv/bin/activate
    - Repository layout: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
2026-07-21 Redact exposed MQTT password from TROUBLESHOOTING.md
    Replace the hardcoded closet-sensor password with a placeholder. The exposed
    value is being rotated on the broker (subscriber account done; sensor account
    pending an ESP32 reflash).
2026-07-21 Cross-platform firmware flash docs + multi-device config hygiene
    - config.example.h: remove stray heredoc wrapper (it wouldn't compile if copied)
    - .gitignore: ignore config-*.h so per-device configs (config-closet-01.h,
    config-closet-lab.h) stay out of git
    - README Firmware: make flash steps cross-platform (macOS/Linux/Windows port
    discovery via `arduino-cli board list`) and document the per-device config
    pattern for running more than one ESP32
2026-09-04 fix(alerts): ASCII-fold the ntfy Title header so push alerts actually send
    HTTP headers are latin-1 (RFC 7230). The alert titles carry emoji -- e.g.
    "⚠️ Closet Sensor Offline" -- so passing one straight into the ntfy `Title`
    header made requests raise:
    'latin-1' codec can't encode characters in position 0-1: ordinal not in range(256)
    notify_ntfy() catches broadly and only logs a warning, so every push
    notification was dropped silently while alerts.log kept filling normally --
    the pipeline looked healthy from the log side.
    Fix: ASCII-fold the header value (falling back to "Closet Monitor" if nothing
    survives) and prepend the full, emoji-intact title to the UTF-8 body, which
    has no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
